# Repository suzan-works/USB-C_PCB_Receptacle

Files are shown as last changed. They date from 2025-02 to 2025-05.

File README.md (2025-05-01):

# USB-C_PCB_Receptacle

プリント基板でできたUSB Type-Cコネクタです。

## 概要
- プリント基板製 USB Type-C リセプタクル
- シェル部分が無いためケーブルに負荷がかかりやすく破損の恐れがあります。試験用、実験用としてご使用ください。

## 外観
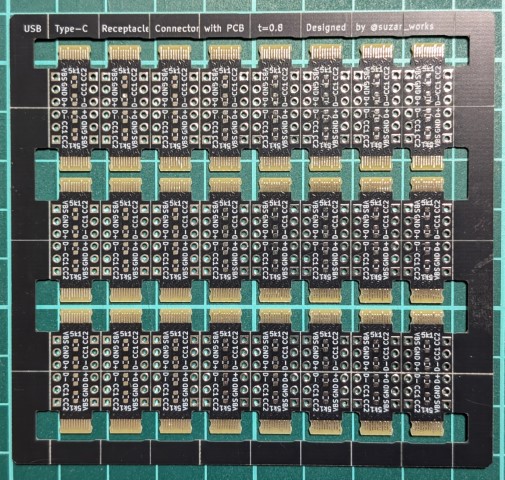
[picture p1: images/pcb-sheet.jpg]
基板全体

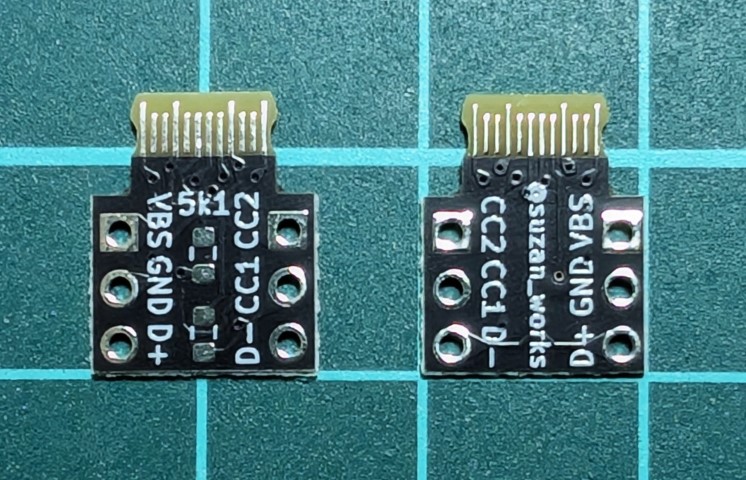
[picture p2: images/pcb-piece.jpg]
子基板表面裏面


## スペック
- シート(集合基板)サイズ：97.28 x 91.28
- ピース(子基板)サイズ：10.16 x 12.7
- 48ピース/1シート
- 基板厚：0.8mm (製造可否は各プリント基板メーカーにお問い合わせください。)
- 信号線：VBUS, GND, CC1, CC2, D+, D-

## KiCad設計データ
- [回路図 (ブラウザで見る)](https://kicanvas.org/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)
- [回路図 (PDF)](/kicad/USB-C_PCB_Receptacle.pdf)
- [基板設計データ (ブラウザで見る)](https://kicanvas.org/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)

## 使用例
- ブレッドボードやユニバーサル基板で、気軽にUSB-Cコネクタが使えます。
- 抵抗5.1kΩを2個実装することで、USB PD 対応電源から簡単に5Vが得られます。
  (プルダウン抵抗5.1kΩをCC1, CC2に実装することで、USB PD仕様に基づいた5V供給を要求する信号が生成され、対応する電源から5Vが供給されます。)
- チップ抵抗5.1kΩ(1608M)が入手できない場合、実験用途に限ってはチップ抵抗10kΩ(1608M)を2個、並列に実装する(2個を重ね合わせてハンダ付けする)ことで約5kΩの抵抗値を得られます。

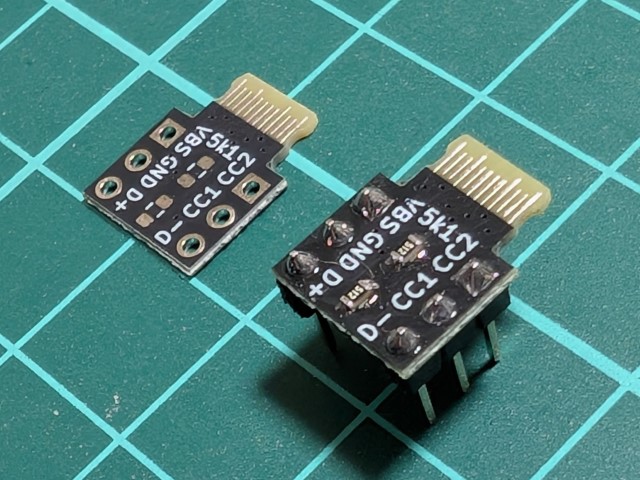
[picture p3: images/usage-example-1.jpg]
使用例1

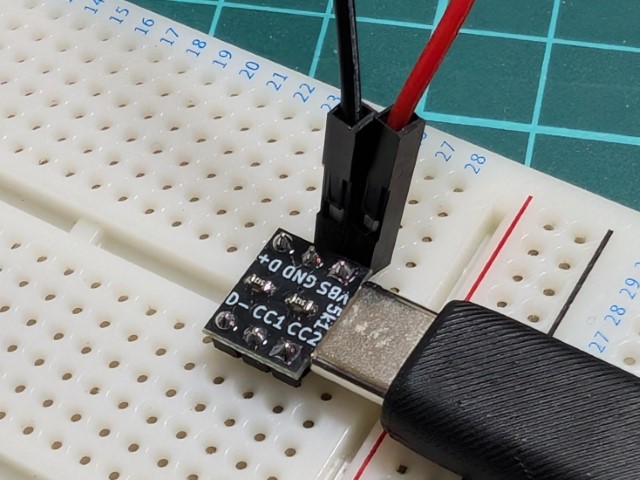
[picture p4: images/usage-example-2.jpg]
使用例2

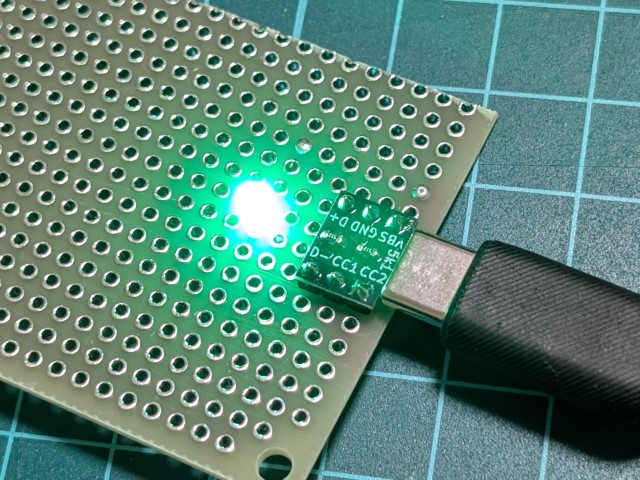
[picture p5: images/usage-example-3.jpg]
使用例3


## 参考
- [CH552E Breakout - CH552Eブレークアウト](https://www.switch-science.com/products/8911) : USB Type-Cエッジコネクタを備えておりケーブルに直接接続可能なマイコンボード。WCH社製8ビットUSBマイコンCH552Eを搭載。
- [Carduino クレジットカードサイズのフィジカルコンピュータ](https://bit-trade-one.co.jp/adakcadu/) : USB Type-Cコネクタ搭載でケーブル接続可能なマイコンボード。クレジットカードサイズのArduino UNO互換機。
- [Carduino USB-C_PCBPLUG](https://github.com/akita11/Carduino/blob/master/Carduino_v41.pretty/USB-C_PCBPLUG.kicad_mod) : CarduinoのUSB Type-CコネクタのKiCadライブラリ。
- [USB Implementers Forum 公式資料](https://www.usb.org/documents)  
　"USB Type-C Cable and Connector Specification Release 2.4" > "Figure 3-1 USB Type-C Receptacle Interface Dimensions"

## ライセンス
[MIT License](https://opensource.org/licenses/MIT)

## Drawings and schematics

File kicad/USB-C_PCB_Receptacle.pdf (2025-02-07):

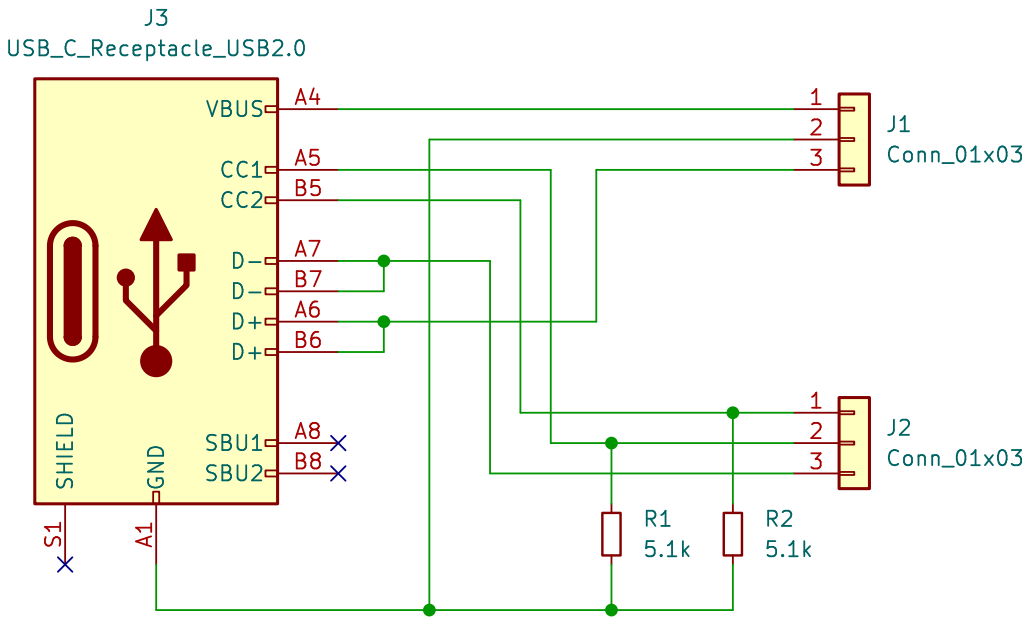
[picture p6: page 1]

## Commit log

2025-02-07 初期コミット
2025-02-07 kicadファイル追加
    [USB-C_PCB_Receptacle.kicad_pcb, USB-C_PCB_Receptacle.kicad_sch]
2025-02-07 README追記
